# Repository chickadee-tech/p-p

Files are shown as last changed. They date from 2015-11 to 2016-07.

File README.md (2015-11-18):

# Chickadee Tech Pololu Power Polystack Board #
This power board provides power to the base control board. It can either be used by mounting a Pololu voltage regulator directly to the pins or by using wire to connect to an existing regulator.

## Documentation ##
See the [wiki](https://github.com/chickadee-tech/p-p/wiki) for documentation.

## Polystack ##
This **power** board is part of the Polystack platform for modular microcontrol systems. More information on the platform can be found at [polystack.org](http://polystack.org).

## Support ##
If you need support with a board you own or have development questions please email support@chickadee.tech or check [chickadee.tech/support](https://chickadee.tech/support) for other ways to get support.

## Contributing ##
Please note that this project is released with a [Contributor Code of Conduct](CODE_OF_CONDUCT.md). By participating in this project you agree to abide by its terms.

### Setup ###
Components and footprints for PCB parts are not included in this repository. Instead, checkout the [chickadee-tech/kicad-libs](https://github.com/chickadee-tech/kicad-libs) repository in the same directory that this repository is checked out in. All part definitions should be relative so that they will load correctly.

### Pull requests ###
For fixes please submit a pull request to the original repository. After the pull request is merged, check the [Chickadee Tech Active Contributor Discount (ACD)](https://chickadee.tech/active-contributor) to see if you are eligible for a discount code to use on your next purchase.

### Derivatives ###
If developing your own version of the Pololu Power board please remove all Chickadee Tech trademarks and follow the [CC-BY license](LICENSE). While not required, please consider open sourcing your modifications so others can learn from your improvements. If you do email support@chickadee.tech and we may choose to add your project to the ACD.

You may also license the Polystack logo for free by emailing support@chickadee.tech. We'll ask for your gerbers to ensure the design complies with specifications laid out [here](https://github.com/chickadee-tech/polystack/wiki) and provide written permission to use the trademark after compliance has been demonstrated.

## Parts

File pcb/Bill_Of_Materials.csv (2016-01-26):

part name | symbol | size (imp) | max current | unit price | units per build | units in stock | order total | Manufacturer ID | source url | datasheet | datasheet2
20 pin receptacle (1.5mm) |  |  |  | $0.66 | 1 | 4 | $0.66 | DF40C-20DS-0.4V(51) | http://www.digikey.com/product-detail/en/DF40C-20DS-0.4V(51)/H11619CT-ND/1969499 | N |  | Total Cost | $3.10
Chickadee Pololu Power v2 | PCB |  |  | $1.50 | 1 | 6 | $1.50 | CKD-P-P-V2 |  | N
R 10k | R2 |  |  | $0.01 | 1 | 979 | $0.01 | RC0603FR-0710KL | http://www.digikey.com/product-detail/en/RC0603FR-0710KL/311-10.0KHRCT-ND/729827 | MF-RES-0603-10K | http://www.yageo.com/NewPortal/yageodocoutput?fileName=/pdf/R-Chip/PYu-RC_Group_51_RoHS_L_3.pdf
R 100k | R1 |  |  | $0.01 | 1 | 55 | $0.01 | RC0603FR-07100KL | http://www.digikey.com/product-detail/en/RC0603FR-07100KL/311-100KHRCT-ND/729836 | MF-RES-0603-100K | http://www.yageo.com/NewPortal/yageodocoutput?fileName=/pdf/R-Chip/PYu-RC_Group_51_RoHS_L_3.pdf
~1.5mm Spacer | Off-Board |  |  | $0.08 | 4 | 81 | $0.32 | 908-060 | http://www.mouser.com/ProductDetail/Bivar/908-060/?qs=GLEjZbDuyKNtD4uKTYVYNA%3D%3D | N | http://www.bivar.com/Portals/0/Products/d.ashx?f=/Portals/0/products/9XX-XXX.pdf
Chickadee Spacer | Off-Board |  |  | $0.60 | 1 | 6 | $0.60 | CKD-SPCR-V2 |  | N

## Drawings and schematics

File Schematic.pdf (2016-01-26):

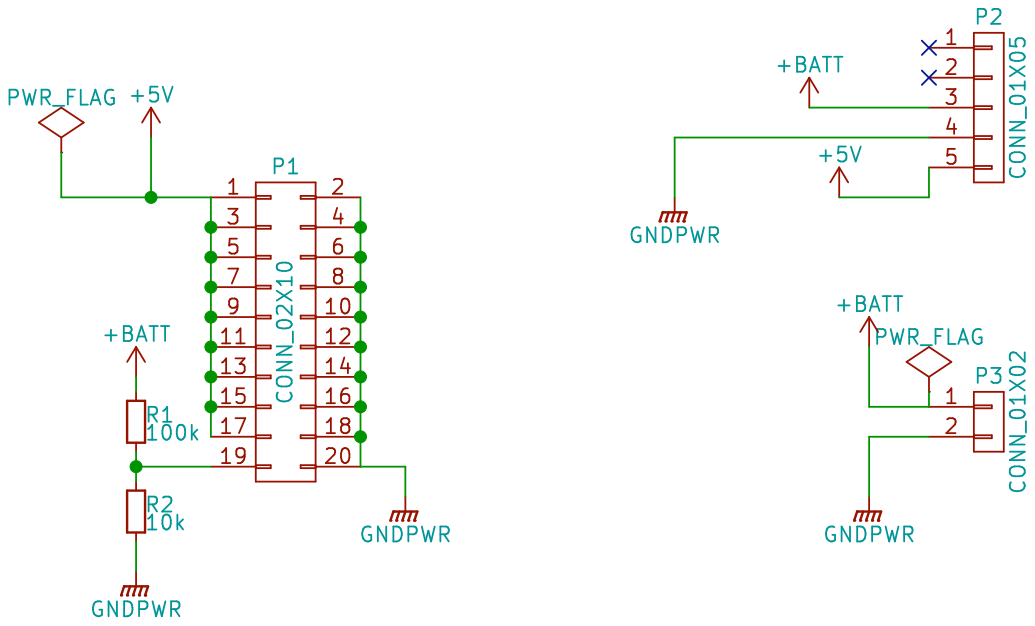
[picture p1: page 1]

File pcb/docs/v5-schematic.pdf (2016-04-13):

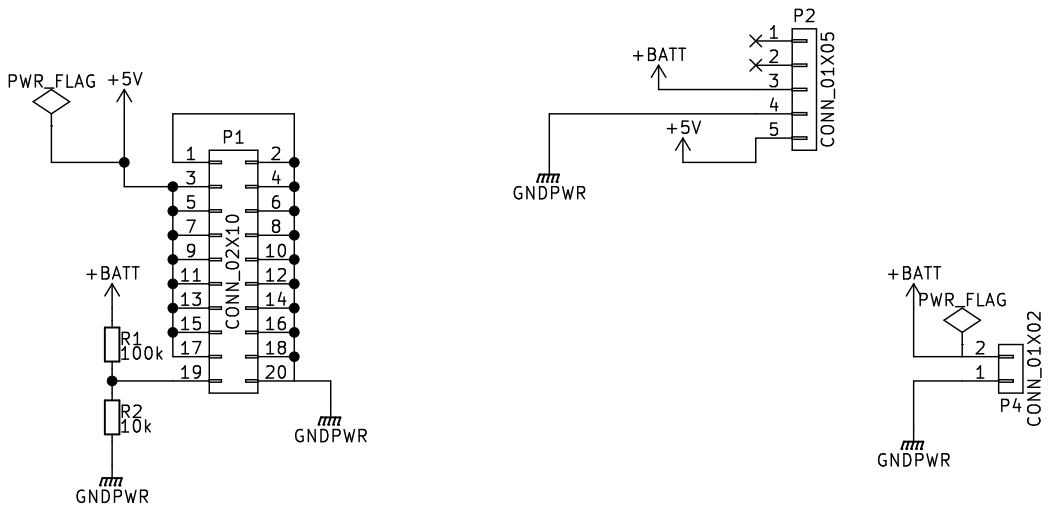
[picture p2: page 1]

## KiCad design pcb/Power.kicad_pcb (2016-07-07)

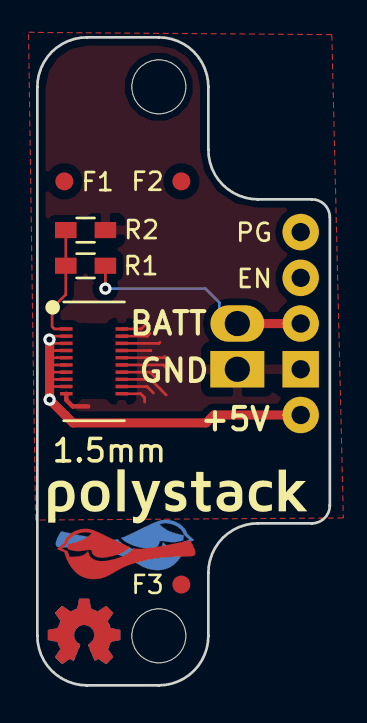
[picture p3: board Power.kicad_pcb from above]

Board: 2 copper layers, 16.2 x 36.0 mm, 10 parts (1 on the bottom side), 4 nets.

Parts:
F1, F2, F3: 1mm; Fiducial
P1: CONN_02X10; DF40-1.5mm-20pin-Receptacle
P2: CONN_01X05; Pin_Header_Straight_1x05
P4: CONN_01X02; 16awg_Pin_Header_Straight_1x02
R1: 100k; R_0603_HandSoldering
R2: 10k; R_0603_HandSoldering
svg2mod, svg2mod#2: G***; polystack-bold-0.75

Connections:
+5V: P1.3, P1.5, P1.7, P1.9, P1.11, P1.13, P1.15, P1.17, P2.5
+BATT: P2.3, P4.2, R1.1
GNDPWR: P1.1, P1.2, P1.4, P1.6, P1.8, P1.10, P1.12, P1.14, P1.16, P1.18, P1.20, P2.4, P4.1, R2.2
unnamed: P1.19, R1.2, R2.1

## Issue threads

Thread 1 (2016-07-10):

Add traces underneath connector

tannewt, 2016-07-10:
To strengthen connection to FR4. Pads come off when the power board is rocked up and down.

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

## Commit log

2015-11-18 v1 of pololu power board
    [Bill_Of_Materials.csv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]
2016-01-11 Add voltage divider to pololu power
    [Power-B.Cu.gbl, Power-B.Mask.gbs, Power-B.SilkS.gbo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]
2016-01-26 Add a voltage divider for the battery to pololu power. Passing in full battery can leads to smoking regulators if it bridges to 5V.
    [Bill_Of_Materials.csv]
2016-01-30 v3 of pololu power. Moved pololu headers to the board edge, centered it to fit narrow standoffs, switched 5v traces to outside to hopefully strengthen the solder joint, and make annular ring of power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
    [Power-B.Cu.gbl, Power-B.Mask.gbs, Power-B.SilkS.gbo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]
2016-03-05 Pololu Power v5 which moves the input holes back out from under the FC.
    [Bill_Of_Materials.csv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]
2016-04-07 Move everything over to pcb.
2016-04-13 Rebrand everything to Polystack and increment versions.
    [Power.kicad_pcb]
2016-04-16 Final gerbers for test manufacturing run.
    [Power-B.Cu.gbl, Power-B.Mask.gbs, Power-B.Paste.gbp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]
2016-06-07 Update polystack logo to bold variant and bump version number.
    [Power.kicad_pcb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]
2016-07-07 Add license information to many files. PCB design files are CC-BY and code is MIT license.
    [Power.kicad_pcb, Power.sch]
2016-07-07 Convert to relative component and footprint paths.

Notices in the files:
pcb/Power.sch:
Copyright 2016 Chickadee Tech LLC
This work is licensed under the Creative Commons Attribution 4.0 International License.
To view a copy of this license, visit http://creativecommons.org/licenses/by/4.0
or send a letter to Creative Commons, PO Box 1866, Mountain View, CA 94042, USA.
